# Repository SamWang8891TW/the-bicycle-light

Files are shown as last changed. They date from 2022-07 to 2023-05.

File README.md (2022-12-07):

# the-bicycle-light
A project which provides users to make their easy-carry, easy-charge, and rich-function bicycle light.
中文使用者請點選上方的連結觀看中文版讀我檔案。

Current version: v0.1.0 (unfinished)
目前版本：v0.1.0 （尚未完成）

Introduction:
This is a bicycle light designed for easy install and remove from most of the bikes. With

PART I, I AM THE USER OF THE PRODUCT AND WANT TO UNDERSTAND HOW TO OPERATE:

1.Main Parts(detailed components press HERE):
    -Front light
        Installed on the front of the bicycle, equipped with a main light.
    -Rear light
        Installed on the rear of the bicycle, equipped with a main light and a pair of signal light.
    -Main control
        Installed on the handle of the bicycle, being as the control(remote) of the whole system.

2.Functionalities(
Note the manual is avilable as a pdf file in the repo(will be uploaded).):

  Front light: 
    -It has a white light strip which can light up the road infront of you. It has a button and a indicate led light. 
    -The button is used as single-operation mode which user decided to use it without a main control connected. When the button is pressed, the light can be switched on or off without the main control.
    -The led is a multi-funtional indicate light. 
        LED ON --> Light is on or the device is charging(when plugged). 
        LED OFF --> Light is off or fully charged(when plugged).
        LED FLAHING --> Battery low.
       
  Rear light:
    -It has three light strip, main read light(red) and left/right light(yellow) for turing singals. It has a button and a indicate led light. 
    -The button is used as single-operation mode which user decided to use it without a main control connected. When the button is pressed, it then disable all ongoing turing signal light and proceed being a switch of the main light. Turning singla light is not accessable while is single-operation mode.
    -The led is a multi-funtional indicate light. 
        LED ON --> Main light is on or the device is charging(when plugged). 
        LED OFF --> Main light is off or fully charged(when plugged).
        LED FLAHING --> Battery low.
   
  Main control:
    -User can control the whole system using is control.
    -It has 4 buttons: Main lights switch, left turning signal, right turning signal and dual flash(warning light).
    -It has 5 LEDs, indicating: Head(Front) light on/off, rear light on/off, left turning signal on/off and right turning signal on/off.
    -When the button is pressed, the vibrator vibrates(and the buzzor beeps if the user has enabled via the code), it then turn the light on or off depend on which button user pressed. To confirm the operation, user can view the indicate LEDs to make sure that they did the operation correctly. Note that the indicate LED does not flash as the real light, constantly on instead.

3.Instructions
    (1). To use the light, first user take out the lights and the main control from the charging case. Please check the battery level by watching the indicating LED is flasing or not.
    (2). To installed the front and rear light, user needs to untie the hook and loop tape, then tie the lights on the prefered place of the bicycle.
    (3). (OPTIONAL) To install the main control, user needs to untie the hook and loop take of the control and do the same thing as the light. Please make sure that user is accessable with their hand during riding the biycle.
    (4). User needs to test every function of the light before the ride, if any issues please create an ISSUE.
    (5). After the ride user then took off the lights and controler and put then back into the charging case. Please wait and see the charging light lids up before closing the case.

Please kindly check the pcb version before doing any operation.
Files:

-pcb:
    Contained the every version of the pcb. Please notice:
      1.Version 0.0.1 has the BJT be as the switch, but failed. So the pin C and E is shorted via soldering.
      2.Resistor and other components naming and ordering may not be as same across multiple versions.

-program:
    Contained the Arduino programm of the device. Currently the programm is suitale for all versions of the PCB.
    
-case:
    Contained f3d and stl files of the case for the lights. This is not necessary since you can designed your own version of it. *f3d is for Fusion360 use only!

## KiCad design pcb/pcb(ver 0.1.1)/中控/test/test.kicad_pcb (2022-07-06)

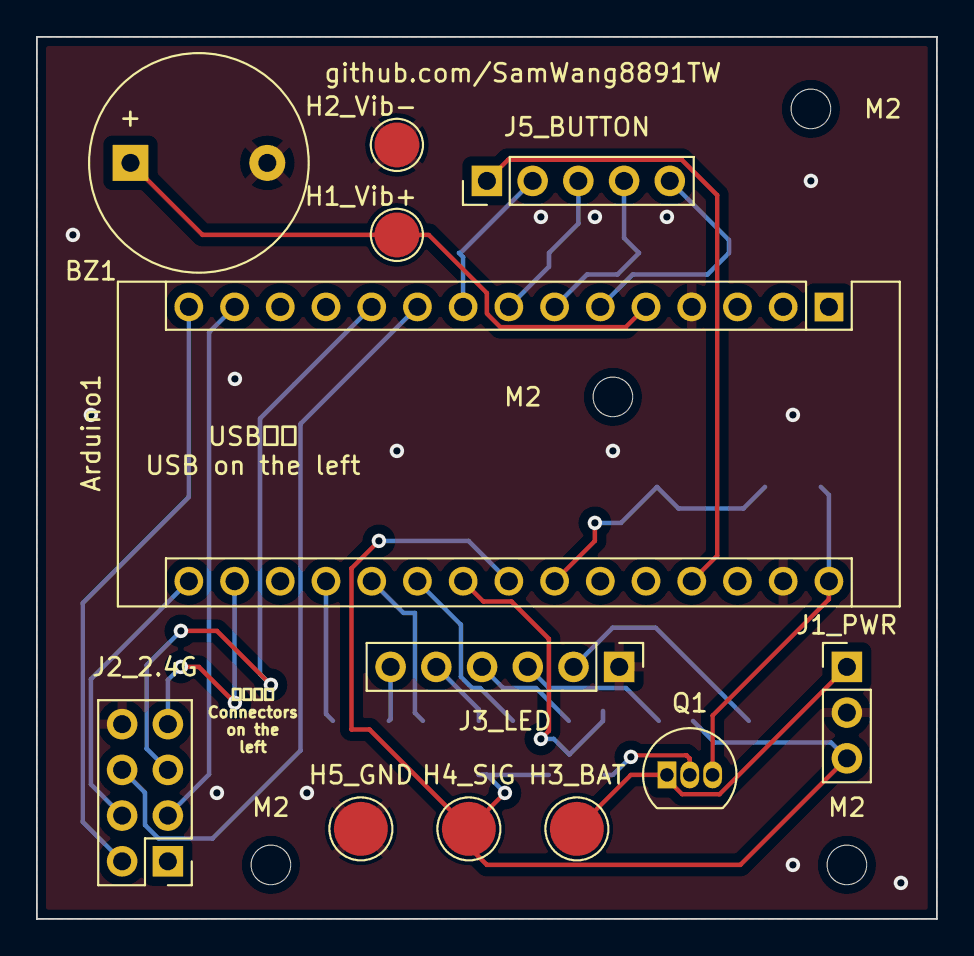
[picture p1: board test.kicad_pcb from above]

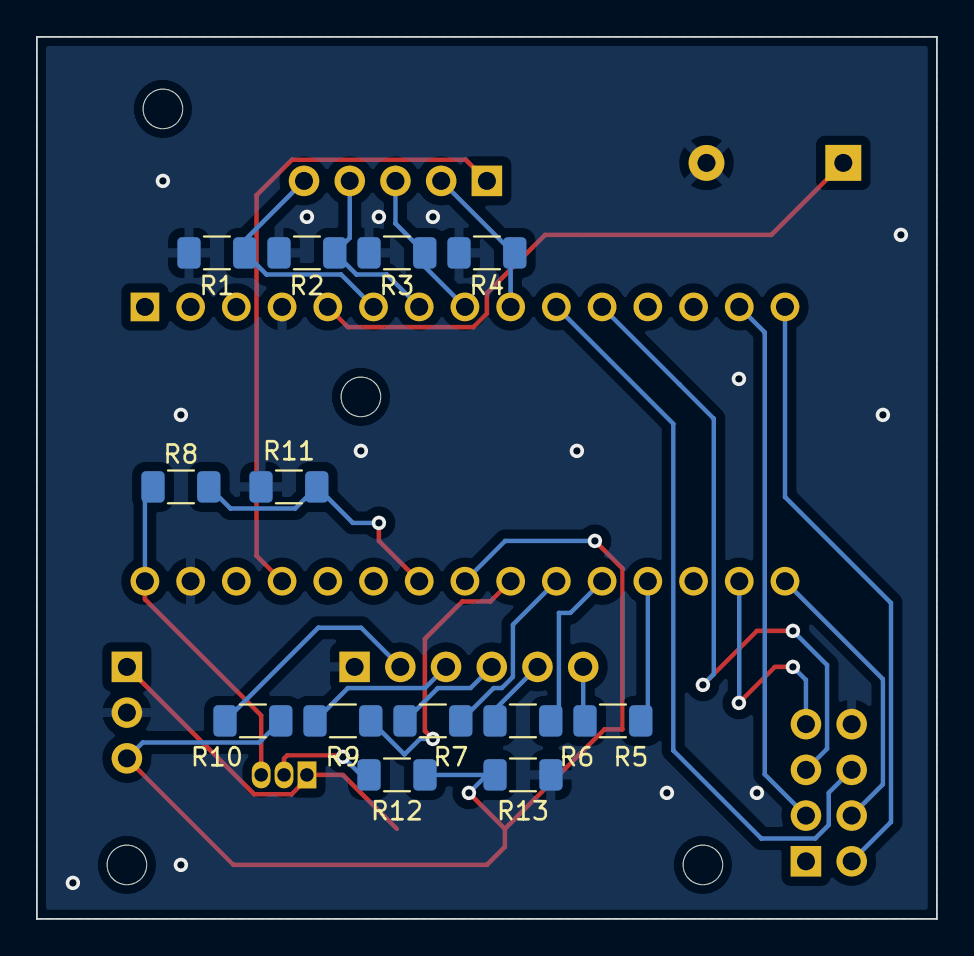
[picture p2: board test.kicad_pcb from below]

Board: 2 copper layers, 50.0 x 49.0 mm, 29 parts (13 on the bottom side), 27 nets.

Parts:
Arduino1: Arduino_Nano
BZ1: Buzzer; Buzzer_12x9.5RM7.6
H1_Vib+, H2_Vib-: Vibrator_Soder_Hole; TestPoint_Pad_D2.5mm
H3_BAT: BAT; TestPoint_Pad_D3.0mm
H4_SIG: SIG; TestPoint_Pad_D3.0mm
H5_GND: GND; TestPoint_Pad_D3.0mm
J1_PWR: PowerCONN; PinHeader_1x03_P2.54mm_Vertical
J2_2.4G: 2.4G_CONN; PinHeader_2x04_P2.54mm_Vertical
J3_LED: LED_CONN; PinHeader_1x06_P2.54mm_Vertical
J5_BUTTON: Button_CONN; PinHeader_1x05_P2.54mm_Vertical
M2, M2#2, M2#3, M2#4: MountingHole_2.2mm_M2
Q1: 2N4355; TO-92_Inline
R1, R2, R3, R4, R5, R6, R7, R9, R10: 330Ω; R_1206_3216Metric_Pad1.30x1.75mm_HandSolder
R8, R11: 500kΩ; R_1206_3216Metric_Pad1.30x1.75mm_HandSolder
R12: 100kΩ; R_1206_3216Metric_Pad1.30x1.75mm_HandSolder
R13: 20kΩ; R_1206_3216Metric_Pad1.30x1.75mm_HandSolder

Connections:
5V: Arduino1.27 (5V), J5_BUTTON.1
Earth: Arduino1.4 (GND), Arduino1.29 (GND), BZ1.2 (+), H2_Vib-.1, H5_GND.1, J1_PWR.2 (Ground), J2_2.4G.8 (GND), J3_LED.1, R1.2, R2.2, R3.2, R4.2, R11.2, R13.2
unnamed: Arduino1.5 (D2), BZ1.1 (-), H1_Vib+.1
unnamed: Arduino1.6 (D3), J5_BUTTON.5, R1.1
unnamed: Arduino1.7 (D4), J5_BUTTON.4, R2.1
unnamed: Arduino1.8 (D5), J5_BUTTON.3, R3.1
unnamed: Arduino1.9 (D6), J5_BUTTON.2, R4.1
unnamed: Arduino1.10 (D7), J2_2.4G.6 (CE)
unnamed: Arduino1.11 (D8), J2_2.4G.5 (CSN)
unnamed: Arduino1.14 (D11(MOSI)), J2_2.4G.3 (MOSI)
unnamed: Arduino1.15 (D12(MISO)), J2_2.4G.2 (MISO)
unnamed: Arduino1.16 (D13), J2_2.4G.4 (SCLK)
unnamed: Arduino1.17 (3V3), J2_2.4G.7 (VCC)
unnamed: Arduino1.19 (A0), R5.2
unnamed: Arduino1.20 (A1), R6.2
unnamed: Arduino1.21 (A2), R7.1
unnamed: Arduino1.22 (A3), R9.1
unnamed: Arduino1.24 (A5), R8.2, R11.1
unnamed: Arduino1.30 (VIN), Q1.3 (C), R8.1
unnamed: H3_BAT.1, J1_PWR.1 (Power), Q1.1 (E)
unnamed: J3_LED.2, R10.1
unnamed: J3_LED.3, R9.2
unnamed: J3_LED.4, R7.2
unnamed: J3_LED.5, R6.1
unnamed: J3_LED.6, R5.1
unnamed: Q1.2 (B), R12.1
SIG: Arduino1.23 (A4), H4_SIG.1, J1_PWR.3 (Charging_Signal), R10.2, R12.2, R13.1

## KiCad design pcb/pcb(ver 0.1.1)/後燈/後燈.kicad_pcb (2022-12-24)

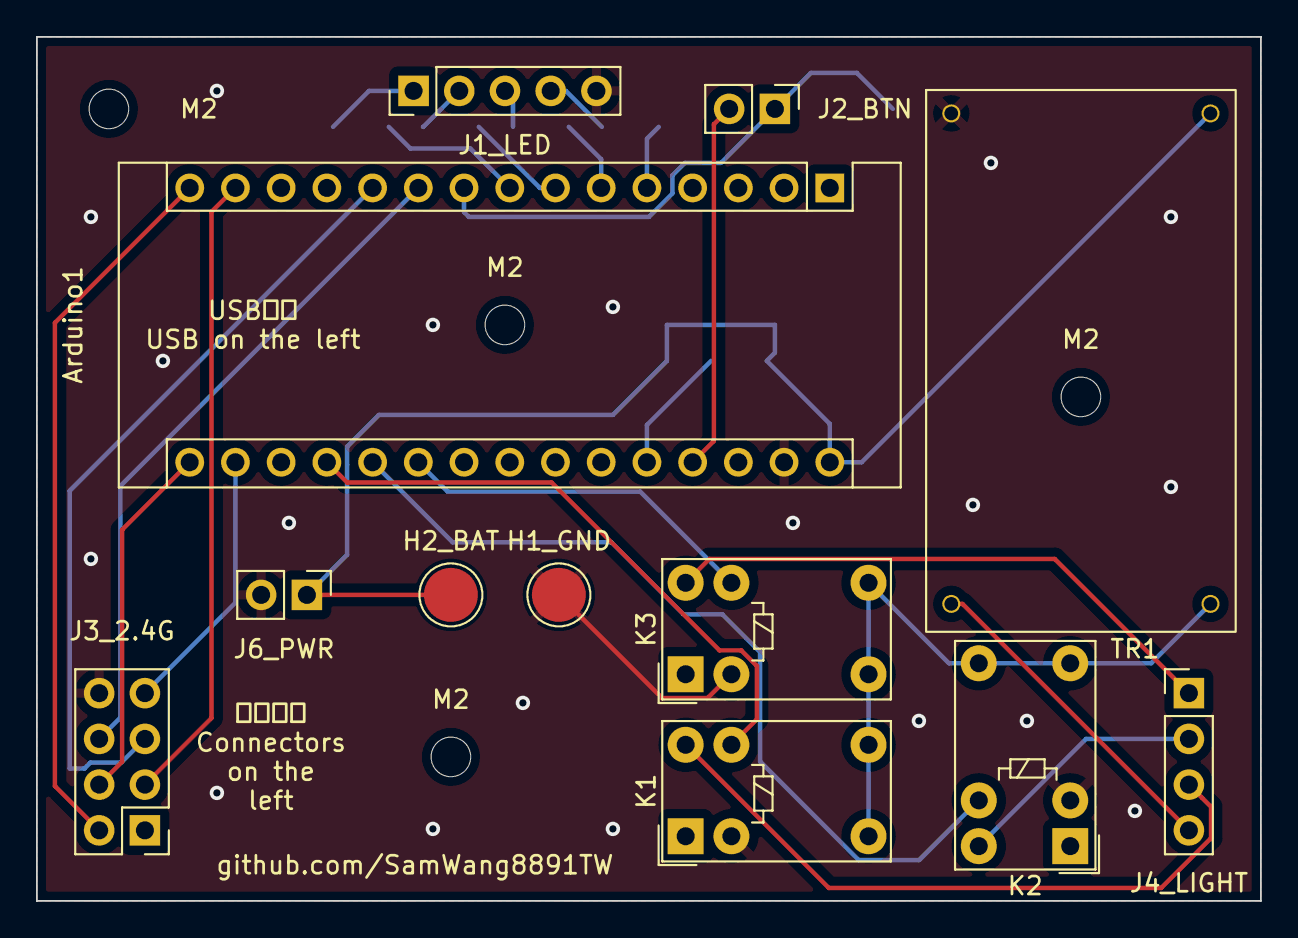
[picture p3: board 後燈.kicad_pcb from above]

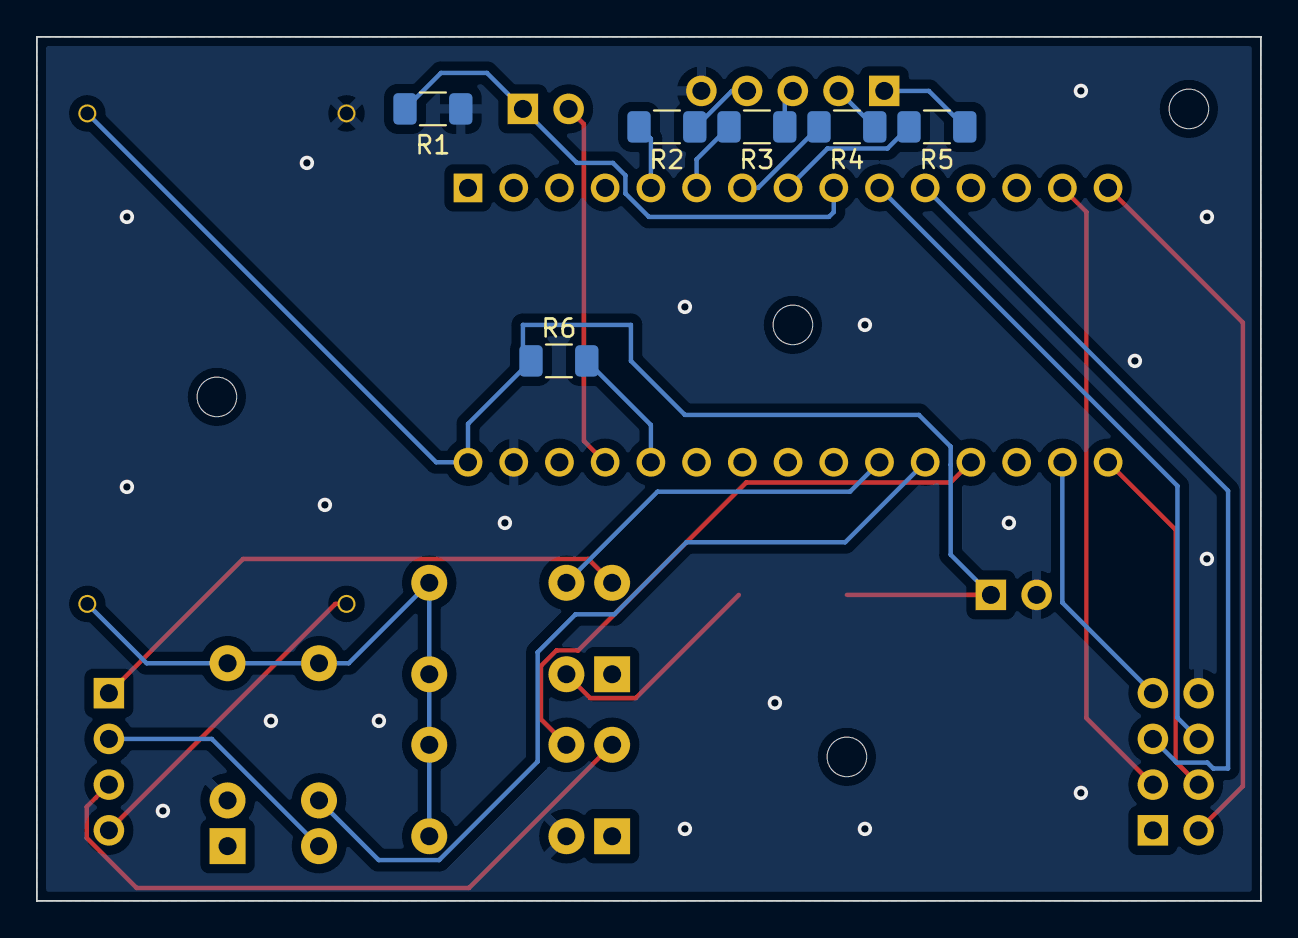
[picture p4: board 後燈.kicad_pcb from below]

Board: 2 copper layers, 68.0 x 48.0 mm, 22 parts (6 on the bottom side), 27 nets.

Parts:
Arduino1: Arduino_Nano
H1_GND: GND; TestPoint_Pad_D3.0mm
H2_BAT: BAT; TestPoint_Pad_D3.0mm
J1_LED: LedCONN; PinHeader_1x05_P2.54mm_Vertical
J2_BTN: BtnCONN; PinHeader_1x02_P2.54mm_Vertical
J3_2.4G: 2.4G_CONN; PinHeader_2x04_P2.54mm_Vertical
J4_LIGHT: LightCONN; PinHeader_1x04_P2.54mm_Vertical
J6_PWR: PWRConn; PinHeader_1x02_P2.54mm_Vertical
K1, K2, K3: G5V-1; Relay_SPDT_Omron_G5V-1
M2, M2#2, M2#3, M2#4: MountingHole_2.2mm_M2
R1, R2, R3, R4, R5: 330Ω; R_1206_3216Metric_Pad1.30x1.75mm_HandSolder
R6: 500kΩ; R_1206_3216Metric_Pad1.30x1.75mm_HandSolder
TR1: Micro3608_1166A_MicroUSB_Module

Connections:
5V: Arduino1.27 (5V), J2_BTN.2
Earth: Arduino1.29 (GND), H1_GND.1, J1_LED.5, J3_2.4G.8 (GND), J6_PWR.2, K1.2, K2.2, K3.2, R1.2, TR1.1 (Vin(-))
unnamed: Arduino1.5 (D2), R2.2
unnamed: Arduino1.6 (D3), R3.2
unnamed: Arduino1.7 (D4), R4.2
unnamed: Arduino1.8 (D5), R5.2
unnamed: Arduino1.9 (D6), J2_BTN.1, R1.1
unnamed: Arduino1.10 (D7), J3_2.4G.6 (CE)
unnamed: Arduino1.11 (D8), J3_2.4G.5 (CSN)
unnamed: Arduino1.14 (D11(MOSI)), J3_2.4G.3 (MOSI)
unnamed: Arduino1.15 (D12(MISO)), J3_2.4G.2 (MISO)
unnamed: Arduino1.16 (D13), J3_2.4G.4 (SCLK)
unnamed: Arduino1.17 (3V3), J3_2.4G.7 (VCC)
unnamed: Arduino1.19 (A0), K1.9
unnamed: Arduino1.20 (A1), K2.9
unnamed: Arduino1.21 (A2), K3.9
unnamed: Arduino1.26 (A7), R6.2
unnamed: J1_LED.1, R5.1
unnamed: J1_LED.2, R4.1
unnamed: J1_LED.3, R3.1
unnamed: J1_LED.4, R2.1
unnamed: J4_LIGHT.1, K3.10
unnamed: J4_LIGHT.2, K2.10
unnamed: J4_LIGHT.3, K1.10
unnamed: J4_LIGHT.4, TR1.3 (Out(-))
unnamed: K1.5, K1.6, K2.5, K2.6, K3.5, K3.6, TR1.4 (Out(+))
VIN: Arduino1.30 (VIN), H2_BAT.1, J6_PWR.1, R6.1, TR1.2 (Vin(+))

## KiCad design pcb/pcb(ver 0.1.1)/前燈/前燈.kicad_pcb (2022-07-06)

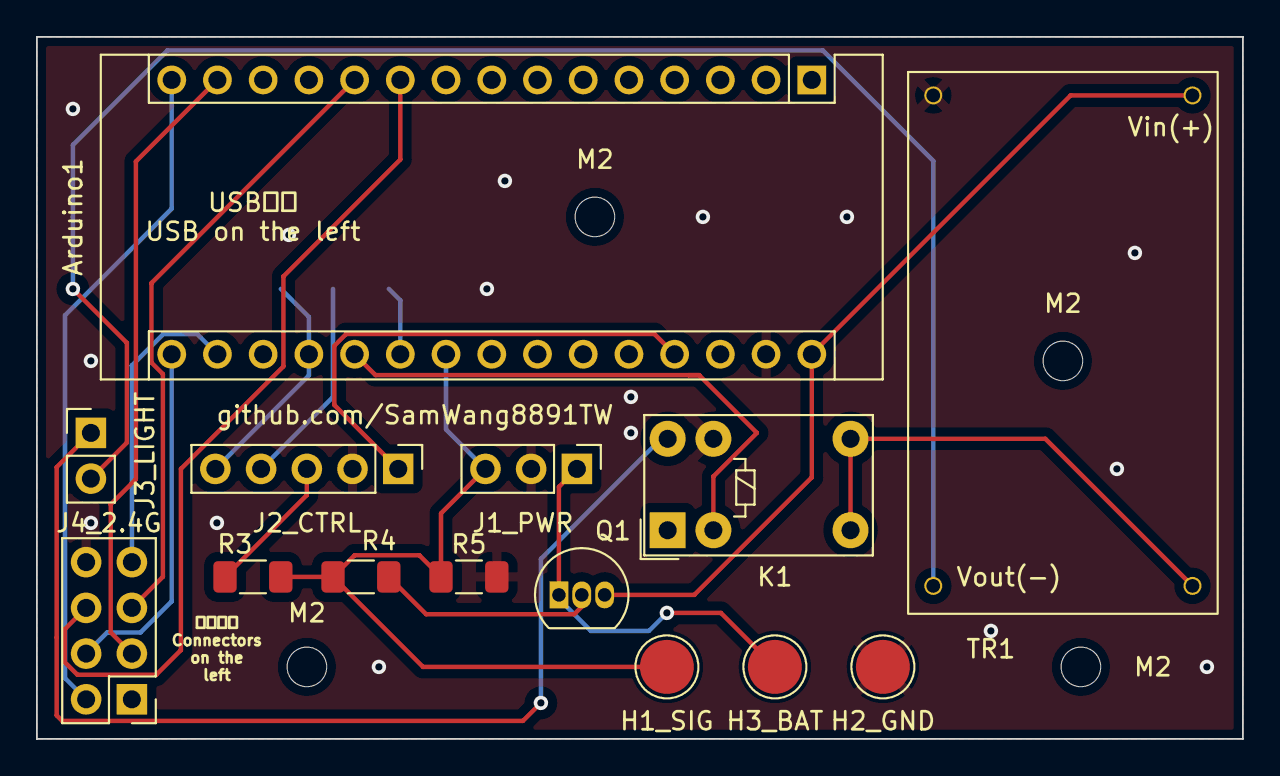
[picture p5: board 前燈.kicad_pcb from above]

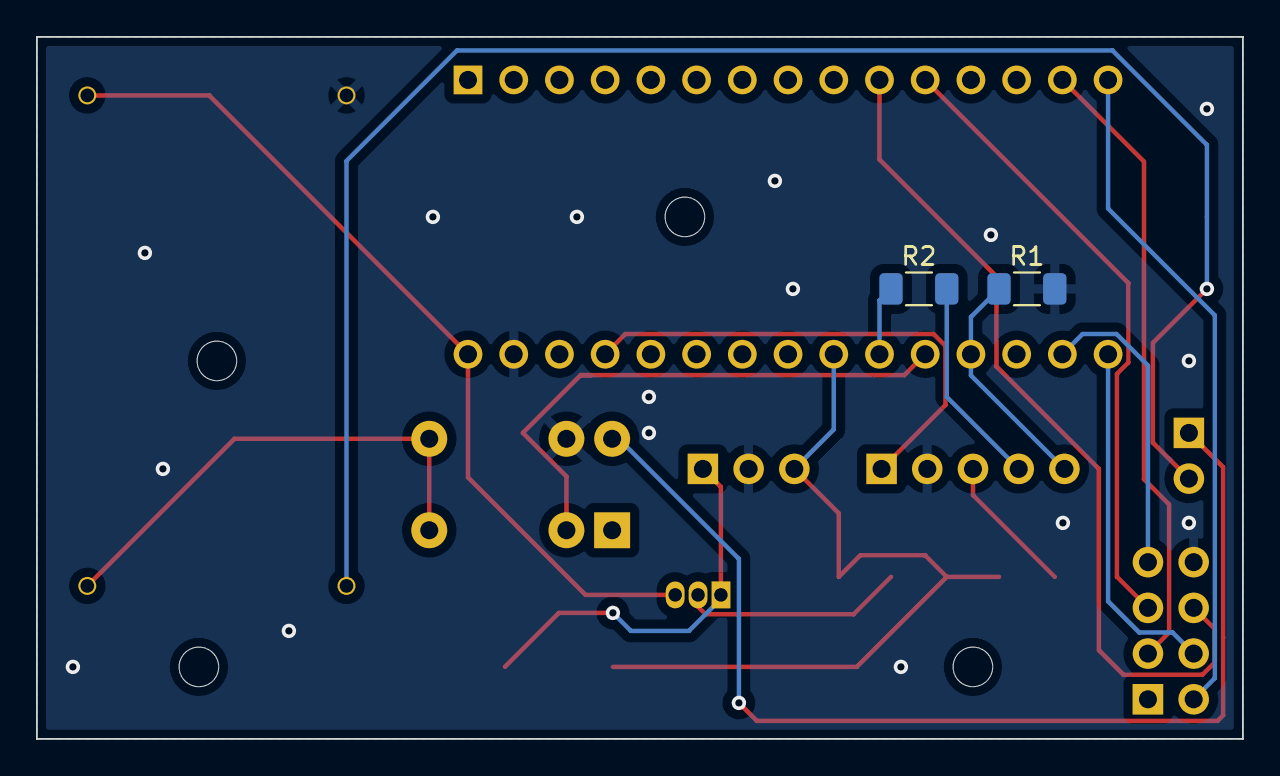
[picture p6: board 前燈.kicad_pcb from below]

Board: 2 copper layers, 67.0 x 39.0 mm, 20 parts (2 on the bottom side), 20 nets.

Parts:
Arduino1: Arduino_Nano
H1_SIG: SIG; TestPoint_Pad_D3.0mm
H2_GND: GND; TestPoint_Pad_D3.0mm
H3_BAT: BAT; TestPoint_Pad_D3.0mm
J1_PWR: PowerCONN; PinHeader_1x03_P2.54mm_Vertical
J2_CTRL: CtrlCONN; PinHeader_1x05_P2.54mm_Vertical
J3_LIGHT: LightCONN; PinHeader_1x02_P2.54mm_Vertical
J4_2.4G: 2.4G_CONN; PinHeader_2x04_P2.54mm_Vertical
K1: G5V-1; Relay_SPDT_Omron_G5V-1
M2, M2#2, M2#3, M2#4: MountingHole_2.2mm_M2
Q1: 2N4355; TO-92_Inline
R1, R2, R3: 330Ω; R_1206_3216Metric_Pad1.30x1.75mm_HandSolder
R4: 100kΩ; R_1206_3216Metric_Pad1.30x1.75mm_HandSolder
R5: 20kΩ; R_1206_3216Metric_Pad1.30x1.75mm_HandSolder
TR1: Micro3608_1166A_MicroUSB_Module

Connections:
Earth: Arduino1.29 (GND), H2_GND.1, J1_PWR.2 (Ground), J2_CTRL.2, J4_2.4G.8 (GND), K1.9, R1.2, R5.2, TR1.1 (Vin(-))
unnamed: Arduino1.10 (D7), J4_2.4G.6 (CE)
unnamed: Arduino1.11 (D8), J4_2.4G.5 (CSN)
unnamed: Arduino1.14 (D11(MOSI)), J4_2.4G.3 (MOSI)
unnamed: Arduino1.15 (D12(MISO)), J4_2.4G.2 (MISO)
unnamed: Arduino1.16 (D13), J4_2.4G.4 (SCLK)
unnamed: Arduino1.17 (3V3), J4_2.4G.7 (VCC)
unnamed: Arduino1.19 (A0), J2_CTRL.5, R1.1
unnamed: Arduino1.20 (A1), K1.2
unnamed: Arduino1.21 (A2), R2.1
unnamed: Arduino1.27 (5V), J2_CTRL.1
unnamed: H3_BAT.1, J1_PWR.1 (Power), Q1.1 (E)
unnamed: J2_CTRL.3, R3.1
unnamed: J2_CTRL.4, R2.2
unnamed: J3_LIGHT.1, K1.10
unnamed: J3_LIGHT.2, TR1.3 (Out(-))
unnamed: K1.5, K1.6, TR1.4 (Out(+))
unnamed: Q1.2 (B), R4.1
SIG: Arduino1.22 (A3), H1_SIG.1, J1_PWR.3 (Charging_Signal), R3.2, R4.2, R5.1
VIN: Arduino1.30 (VIN), Q1.3 (C), TR1.2 (Vin(+))

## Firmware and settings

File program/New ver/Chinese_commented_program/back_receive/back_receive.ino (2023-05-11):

#define flashing_cycle 800        //定義方向燈及警示燈閃爍間隔（微秒）
#define enable_serial_debug true  //是否啟序列除錯


#define CE 7        //2.4G 無線模組的 CE 腳位
#define CSN 8       //2.4G 無線模組的 CSN 腳位
#define r_mid A1    //大燈(中間)繼電器腳位 A0
#define r_left A2  //左邊方向燈繼電器腳位 A2
#define r_right A3   //右邊方向燈繼電器腳位 A1
#define l_mid 5     //大燈指示led燈腳位
#define l_left 6    //左轉指示led燈腳位
#define l_right 9   //右轉指示led燈腳位
#define l_state 1000
#define bt_main 6  //大燈手動開啟的按鍵腳位


#include <SPI.h>
#include "RF24.h"  //RF24.h by nRF24 "https://github.com/nRF24/RF24"
#include <math.h>



bool b_mid = false;                     //大燈按鈕是否觸發的布林函數
bool b_left = false;                    //左轉燈按鈕是否觸發的布林函數
bool b_flash = false;                   //左右燈是否觸發閃爍程式的布林函數
bool b_right = false;                   //右轉燈按鈕是否觸發的布林函數
bool b_leftstats = false;               //是否正在使用左轉燈的布林函數
bool b_rightstats = false;              //是否正在使用左轉燈的布林函數
bool b_midorgstate = false;             //大燈原本狀態
unsigned long flashpreviousMillis = 0;  //用以儲存上一次閃爍的時間
unsigned long midpreviousMillis, offpreviousMillis, dualpreviousMillis, leftpreviousMillis, rightpreviousMillis = 0;



//2.4G 無限模組
RF24 rf24(CE, CSN);           //定義2.4G無線模組的腳位
const byte addr[] = "1Node";  //定義2.4G無限模組的位置
const byte pipe = 1;          //指定通道編號


/*
定義接收訊號
a --> 大燈開啟
b --> 大燈關閉
c --> 左轉燈開啟
d --> 右轉燈開啟
e --> 方向燈及警示燈關閉
f --> 警示燈開啟
*/
char on[32] = "a";
char off[32] = "b";
char lon[32] = "c";
char ron[32] = "d";
char foff[32] = "e";
char dual[32] = "f";




void setup() {
  //啟用序列監控
  if (enable_serial_debug)
    Serial.begin(9600);

  rf24.begin();                      //初始化2.4G無線模組
  rf24.setChannel(83);               //設定頻道編號
  rf24.setPALevel(RF24_PA_MIN);      //設定功率
  rf24.setDataRate(RF24_1MBPS);      //設定傳輸速率
  rf24.openReadingPipe(pipe, addr);  //開啟通道和位址
  rf24.startListening();             //開始監聽無線廣播
  Serial.print("Radio initialized! Receiving!\n");
  Serial.print("CH83, 1MBPS, pipe1, addr=1Node\n");

  //設定腳位狀態
  pinMode(r_mid, OUTPUT);
  pinMode(r_left, OUTPUT);
  pinMode(r_right, OUTPUT);
  pinMode(l_state, OUTPUT);
  pinMode(l_mid, OUTPUT);
  pinMode(l_left, OUTPUT);
  pinMode(l_right, OUTPUT);
  pinMode(bt_main, INPUT);

  //讓所有燈都亮過一遍檢查錯誤
  Serial.println("Testing lights...");
  digitalWrite(r_left, HIGH);
  digitalWrite(l_left, HIGH);
  delay(1000);
  digitalWrite(r_left, LOW);
  digitalWrite(l_left, LOW);
  delay(1000);
  digitalWrite(r_mid, HIGH);
  digitalWrite(l_mid, HIGH);
  delay(1000);
  digitalWrite(r_mid, LOW);
  digitalWrite(l_mid, LOW);
  delay(1000);
  digitalWrite(r_right, HIGH);
  digitalWrite(l_right, HIGH);
  delay(1000);
  digitalWrite(r_right, LOW);
  digitalWrite(l_right, LOW);

  Serial.print("Radio initialized! Receiving!");
  Serial.print("CH83, 1MBPS, pipe1, addr = 1Node");
  Serial.println("Starting loop:");
}

void loop() {
  //**********************
  //****PART1 寫入繼電器****
  //**********************


  //將大燈的布林函數狀態寫入繼電器及指示燈
  digitalWrite(r_mid, b_mid);
  digitalWrite(l_mid, b_mid);

  while (b_flash) {  //讓方向燈及警示燈閃爍
    unsigned long currentMillis = millis();
    if (currentMillis - flashpreviousMillis >= flashing_cycle) {
      flashpreviousMillis = currentMillis;

      if (b_right == true && b_rightstats) {
        b_right = false;
        digitalWrite(r_right, LOW);
        digitalWrite(l_right, LOW);
      } else if (b_right == false && b_rightstats) {
        b_right = true;
        //Serial.println("right_tick");
        digitalWrite(r_right, HIGH);
        digitalWrite(l_right, HIGH);
      }

      if (b_left == true && b_leftstats) {
        b_left = false;
        digitalWrite(r_left, LOW);
        digitalWrite(l_left, LOW);
      } else if (b_left == false && b_leftstats) {
        b_left = true;
        //Serial.println("left_tick");
        digitalWrite(r_left, HIGH);
        digitalWrite(l_left, HIGH);
      }
    }
    break;
  }




  //**********************
  //*****PART2 偵測信號*****
  //**********************


  //偵測按鈕是否按下並針對動作作動
  // if (digitalRead(bt_main) == true) {
  //   b_mid = !b_mid;
  //   b_left = false;
  //   b_leftstats = false;
  //   b_rightstats = false;
  //   b_right = false;
  //   b_flash = false;
  //   b_midorgstate = false;
  //   Serial.println("Button pressed, turning signal light off and change mid light stats.");
  // }

  //2.4G無線模組接收訊號
  if (rf24.available(&pipe)) {
    char msg[32] = "";
    rf24.read(&msg, sizeof(msg));  //將獨到的訊息存入msg

    Serial.println(msg);

    if (strcmp(msg, on) == 0) {  //判斷接收到的訊息是否為開大燈
      Serial.println("Mid on!");
      if (b_flash) {
        unsigned long currentMillis = millis();
        if (currentMillis - midpreviousMillis >= 2000) {
          //Serial.println(midpreviousMillis);
          //Serial.println(currentMillis);
          b_midorgstate = !b_midorgstate;
          Serial.print("org state to:");
          Serial.println(b_midorgstate);
          //Serial.println(currentMillis);
          midpreviousMillis = currentMillis;
        }
      } else
        b_mid = true;


    } else if (strcmp(msg, off) == 0) {  //判斷接收到的訊息是否為關大燈
      Serial.println("Mid off!");
      if (b_flash)
        b_midorgstate = false;
      else
        b_mid = false;

    } else if (strcmp(msg, lon) == 0) {  //判斷接收到的訊息是否為開啟左邊方向燈
      Serial.println("Left on!");

      flashpreviousMillis = millis() - 100000;  //讓閃爍程式馬上觸發

      unsigned long currentMillis = millis();
      if (currentMillis - rightpreviousMillis > 2000) {
        if (b_mid == false && b_rightstats == false) {  //如果大燈未開啟及且另一邊的方向燈未啟用，則先開啟大燈再開啟方向燈以便後車辨認方向燈方向
          b_midorgstate = false;                        //將原本大燈的狀態儲存，以便之後關閉方向燈之後還原大燈狀態
          b_mid = true;
        } else if (b_mid && b_rightstats == false) {
          b_midorgstate = true;
        }
        rightpreviousMillis = currentMillis;
      }
      b_right = false;  //關閉另一邊的方向燈
      b_rightstats = false;
      b_flash = true;
      b_left = true;
      b_leftstats = true;


    } else if (strcmp(msg, ron) == 0) {  //判斷接收到的訊息是否為開啟右邊方向燈
      Serial.println("Right on!");
      flashpreviousMillis = millis() - 100000;  //讓閃爍程式馬上觸發

      unsigned long currentMillis = millis();
      if (currentMillis - leftpreviousMillis > 2000) {
        if (b_mid == false && b_leftstats == false) {  //如果大燈未開啟及另一邊的方向燈未啟用，則先開啟大燈再開啟方向燈以便後車辨認方向燈方向
          b_midorgstate = false;                       //將原本大燈的狀態儲存，以便之後關閉方向燈之後還原大燈狀態
          b_mid = true;
        } else if (b_mid && b_leftstats == false) {
          b_midorgstate = false;
        }
        leftpreviousMillis = currentMillis;
      }
      b_left = false;  //關閉另一邊的方向燈
      b_leftstats = false;
      b_flash = true;
      b_right = false;
      b_rightstats = true;


    } else if (strcmp(msg, foff) == 0) {  //判斷接收到的訊息是否關閉方向燈或是警示燈
      Serial.println("Flash off!");
      digitalWrite(r_right, LOW);
      digitalWrite(l_right, LOW);
      digitalWrite(r_left, LOW);
      digitalWrite(l_left, LOW);

      unsigned long currentMillis = millis();
      if (currentMillis - offpreviousMillis > 2000) {
        if (b_midorgstate) {
          Serial.println("org state 1 --> b_mid to true");
          b_mid = true;
        } else {
          Serial.println("run");
          b_mid = false;
        }
        offpreviousMillis = currentMillis;
      }
      b_midorgstate = false;
      b_flash = false;
      b_right = false;
      b_left = false;
      b_rightstats = false;
      b_leftstats = false;


    } else if (strcmp(msg, dual) == 0) {  //判斷接收到的訊息是開啟警示燈
      Serial.println("Dual Flash!");

      flashpreviousMillis = millis() - 100000;  //讓閃爍程式馬上觸發

      unsigned long currentMillis = millis();
      if (currentMillis - dualpreviousMillis > 2000) {
        if (b_mid == false && b_left == false && b_right == false) {  //如果大燈未開啟及方向燈未啟用，則先開啟大燈再開啟方向燈以便後車辨認方向燈方向
          b_midorgstate = false;                                      //將原本大燈的狀態儲存，以便之後關閉方向燈之後還原大燈狀態
          b_mid = true;
        } else if (b_mid && b_left == false && b_right == false) {
          b_midorgstate = true;
        }
        dualpreviousMillis = currentMillis;
      }
      b_left = true;
      b_right = true;
      b_flash = true;
      b_rightstats = true;
      b_leftstats = true;


    } else {
      Serial.println("Ignore!");
    }
  }
}

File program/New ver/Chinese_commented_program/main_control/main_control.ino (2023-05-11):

#define bzsw true                 //是否啟用蜂鳴器及震動
#define enable_serial_debug true  //是否啟序列除錯


#define CE 7        //2.4G 無線模組的 CE 腳位
#define CSN 8       //2.4G 無線模組的 CSN 腳位
#define l_mid A2  //大燈指示led燈腳位
#define l_left A3 //左轉方向燈指示led燈腳位
#define l_right A4 //右轉方向燈指示led燈腳位
#define l_stats A0  //狀態指示led燈腳位 
#define bt_mid 4    //大燈(中間)按鈕腳位
#define bt_left 5   //左轉方向燈按鈕腳位
#define bt_right 3  //右轉方向燈按鈕腳位
#define bt_dual 6   //警示燈按鈕腳位
#define vmotor 9    //震動馬達繼電器腳位
#define bz 2        //蜂鳴器繼電器腳位
#define bat_volume_detect A6 //偵測電量的腳位


#include <SPI.h>
#include "RF24.h"  //RF24.h by nRF24 "https://github.com/nRF24/RF24"


bool b_mid = false;      //大燈按鈕是否觸發的布林函數
bool b_left = false;     //左轉燈按鈕是否觸發的布林函數
bool b_right = false;    //右轉燈按鈕是否觸發的布林函數
bool b_dual = false;     //警示燈是否觸發的布林函數
bool b_flash = false;    //決定左右轉方向燈動作的布林函數
bool b_mstats = false;   //是否正在使用大燈燈的布林函數
bool b_lstats = false;   //是否正在使用左轉燈的布林函數
bool b_rstats = false;   //是否正在使用右轉燈的布林函數
bool b_dfstats = false;  //是否正在使用警示燈的布林函數

int bat; //電量


//2.4G 無限模組
RF24 rf24(CE, CSN);           //定義2.4G無線模組的腳位
const byte addr[] = "1Node";  //定義2.4G無限模組的位置


/*
定義接收訊號
a --> 大燈開啟
b --> 大燈關閉
c --> 左轉燈開啟
d --> 右轉燈開啟
e --> 方向燈及警示燈關閉
f --> 警示燈開啟
*/
char on[32] = "a";
char off[32] = "b";
char lon[32] = "c";
char ron[32] = "d";
char foff[32] = "e";
char dual[32] = "f";




void setup() {
  //啟用序列監控
  Serial.begin(9600);

  rf24.begin();                  //初始化2.4G無線模組
  rf24.setChannel(83);           //設定頻道編號
  rf24.openWritingPipe(addr);    //設定通道位址
  rf24.setPALevel(RF24_PA_MIN);  //設定功率
  rf24.setDataRate(RF24_1MBPS);  //設定傳輸速率
  rf24.stopListening();          //停止偵聽-->設定成發射模式

  //設定腳位狀態
  pinMode(bt_mid, INPUT);
  pinMode(bt_left, INPUT);
  pinMode(bt_right, INPUT);
  pinMode(bt_dual, INPUT);
  pinMode(l_mid, OUTPUT);
  pinMode(l_left, OUTPUT);
  pinMode(l_right, OUTPUT);
  pinMode(l_stats, OUTPUT);
  pinMode(bz, OUTPUT);
  pinMode(vmotor, OUTPUT);
  pinMode(bat_volume_detect, INPUT);

  //讓所有燈都亮過一遍檢查錯誤
  Serial.println("Testing lights...");
  digitalWrite(l_mid, HIGH);
  delay(1000);
  digitalWrite(l_mid, LOW);
  delay(1000);
  digitalWrite(l_left, HIGH);
  delay(1000);
  digitalWrite(l_left, LOW);
  delay(1000);
  digitalWrite(l_right, HIGH);
  delay(1000);
  digitalWrite(l_right, LOW);
  delay(1000);
  digitalWrite(l_stats, HIGH);
  delay(1000);
  digitalWrite(l_stats, LOW);


  beep();
  Serial.println("Radio initialized! Sending!");
  Serial.println("CH83, 1MBPS, addr = 1Node");
  Serial.println("Starting loop!");
}

void loop() {
  //**********************
  //****PART0 電量讀取*****
  //**********************
  
  bat = analogRead(bat_volume_detect);
  Serial.println(bat);  
  

  //**********************
  //****PART1 偵測按鈕*****
  //**********************
  if (digitalRead(bt_mid) == true) { //判斷開關大燈的按鈕是否按下
    delay(200);
    if (digitalRead(bt_mid) == true)
      Serial.println("Main trig");
    b_mid = true;
    beep();

  } else if (digitalRead(bt_left) == true) { //判斷開關左轉方向燈的按鈕是否按下
    delay(200);
    if (digitalRead(bt_left) == true)
      Serial.println("Left trig");
    b_left = true;
    beep();

  } else if (digitalRead(bt_right) == true) { //判斷開關右轉方向燈的按鈕是否按下
    delay(200);
    if (digitalRead(bt_right) == true)
      Serial.println("Right trig");
    b_right = true;
    beep();

  } else if (digitalRead(bt_dual) == true) { //判斷開關警示燈的按鈕是否按下
    delay(200);
    Serial.println("Dual trig");
    b_dual = true;
    beep();

  }


  //**********************
  //****PART2 發送訊號*****
  //**********************
  if (b_mid == true) { //傳送開關大燈訊息
    b_mid = false;
    Serial.print("Main send sig");
    b_mstats = !b_mstats;

    if (b_mstats) {
      Serial.println("mid on");
      rf24.write(&on, sizeof(on));
      rf24.write(&on, sizeof(on));
      rf24.write(&on, sizeof(on));
      digitalWrite(l_mid, HIGH);
    } else {
      Serial.println("mid off");
      rf24.write(&off, sizeof(off));
      rf24.write(&off, sizeof(off));
      rf24.write(&off, sizeof(off));
      digitalWrite(l_mid, LOW);
    }

  } else if (b_left == true) { //傳送開關左轉方向燈訊息
    Serial.println("l_triggered");
    b_left = false;
    b_dfstats = false;

    if (b_rstats) {
      b_rstats = false;
      b_lstats = true;
      b_flash = true;
    } else if (b_lstats) {
      b_lstats = false;
      b_flash = false;
    } else {
      b_lstats = true;
      b_flash = true;
    }

    if (b_flash) {
      Serial.println("lon");
      rf24.write(&foff, sizeof(foff));
      rf24.write(&foff, sizeof(foff));
      rf24.write(&foff, sizeof(foff));
      rf24.write(&lon, sizeof(lon));
      rf24.write(&lon, sizeof(lon));
      rf24.write(&lon, sizeof(lon));
      digitalWrite(l_left, HIGH);
    } else {
      Serial.println("flash off");
      rf24.write(&foff, sizeof(foff));
      rf24.write(&foff, sizeof(foff));
      rf24.write(&foff, sizeof(foff));
      digitalWrite(l_left, LOW);
      digitalWrite(l_right, LOW);
    }

  } else if (b_right == true) { //傳送開關右轉方向燈訊息
    Serial.println("r_triggered");

    b_right = false;
    b_dfstats = false;

    if (b_lstats) {
      b_lstats = false;
      b_rstats = true;
      b_flash = true;
    } else if (b_rstats) {
      b_rstats = false;
      b_flash = false;
    } else {
      b_rstats = true;
      b_flash = true;
    }


    if (b_flash) {
      Serial.println("ron");
      rf24.write(&foff, sizeof(foff));
      rf24.write(&foff, sizeof(foff));
      rf24.write(&foff, sizeof(foff));
      rf24.write(&ron, sizeof(ron));
      rf24.write(&ron, sizeof(ron));
      rf24.write(&ron, sizeof(ron));
      digitalWrite(l_right, HIGH);
    } else {
      Serial.println("flash off");
      rf24.write(&foff, sizeof(foff));
      rf24.write(&foff, sizeof(foff));
      rf24.write(&foff, sizeof(foff));
      digitalWrite(l_left, LOW);
      digitalWrite(l_right, LOW);
    }

  } else if (b_dual) { //傳送開關警示燈訊息
    Serial.println("d_triggered");
    b_dual = false;
    b_lstats = false;
    b_rstats = false;
    if (b_dfstats) {
      Serial.println("flash off");
      rf24.write(&foff, sizeof(foff));
      rf24.write(&foff, sizeof(foff));
      rf24.write(&foff, sizeof(foff));
      digitalWrite(l_left, LOW);
      digitalWrite(l_right, LOW);
    } else {
      Serial.println("dual on");
      rf24.write(&foff, sizeof(foff));
      rf24.write(&foff, sizeof(foff));
      rf24.write(&foff, sizeof(foff));
      rf24.write(&dual, sizeof(dual));
      rf24.write(&dual, sizeof(dual));
      rf24.write(&dual, sizeof(dual));
      digitalWrite(l_left, HIGH);
      digitalWrite(l_right, HIGH);
    }
    b_dfstats = !b_dfstats;

  }
}


void beep() { //用蜂鳴器及震動馬達及狀態燈告知使用者
  digitalWrite(l_stats, HIGH);
  if (bzsw == true)
    digitalWrite(bz, HIGH);
  digitalWrite(vmotor, HIGH);
  delay(100);
  digitalWrite(bz, LOW);
  delay(100);
  digitalWrite(vmotor, LOW);
  digitalWrite(l_stats, LOW);
}

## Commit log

2022-07-06 Add files via upload
    v0.1 alpha
    [test.kicad_pcb, test.kicad_sch, 前燈.kicad_pcb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]
2022-12-07 Progress upload
    [MT3608.kicad_pcb, MT3608.kicad_sch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]
